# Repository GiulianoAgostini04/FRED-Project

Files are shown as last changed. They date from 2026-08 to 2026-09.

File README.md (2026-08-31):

# FRED-Project
Real-time concentration monitoring system based on frontal-lobe EEG signals. Features a custom PCB designed with TinkerCAD and KiCad, OpenBCI Ganglion and Arduino UNO for signal acquisition, display, and frequency-band analysis for classification. Includes circuit schematics, hardware prototyping, and a VHDL model of the decision logic.

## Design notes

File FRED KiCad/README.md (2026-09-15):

# FRED: KiCad Section

This repository contains the KiCad design files for FRED (Focus-Related Encephalographic Device), a custom EEG acquisition board developed for an electronic engineering course project.

The board handles the full analog front-end for EEG signal acquisition (electrode input, protection, channel multiplexing, instrumentation amplification, filtering, galvanic isolation, output buffering) and a digital channel-selection block, and sends the processed signal to an Arduino for further analysis and display.

## Board overview

The design includes:

- Electrode input stage with protection and a DRL (Driven Right Leg) reference stage for common-mode rejection
- CD4052B dual multiplexer for electrode channel selection
- INA128 instrumentation amplifier
- Sallen-Key high-pass filter (fc = 1 Hz)
- Fixed-gain amplification stage (A = 10)
- 50 Hz Twin-T notch filter
- Galvanic isolation stage based on NE555 PWM modulation, a 4N35 optocoupler, and Sallen-Key demodulation
- Anti-aliasing band-pass filter and output buffer toward the Arduino ADC
- Digital block for channel selection (slide switches, 74HC74 flip-flop, 74HC04/74HC08 logic, status LEDs)

Note: intermediate export files (`.cad`, `.cmp`, `.dsn`, `.emn`, `.emp`, `.hyp`, `.wrl`) and auto-generated check reports (`DRC.rpt`, `ERC.rpt`, `report.txt`) are not versioned, since they can be regenerated at any time from the project files.

## Tools used

| Tool | Purpose |
|---|---|
| KiCad 10.0 | Schematic and PCB layout |

## How to open the project

1. Clone the repository.
2. Open `FRED_Electrical_Scheme_KiCAD.kicad_pro` with KiCad 10.0 or later.
3. Schematic and PCB print PDFs are available in the `PDF/` folder for a quick look without opening KiCad.

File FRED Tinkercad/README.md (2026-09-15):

# FRED: TinkerCAD Section

The circuit reproduces the full analog front-end on breadboards, together with the digital channel-selection block, and connects to an Arduino Uno driving an LCD 16x2 display.

## Circuit overview

The prototype implements, stage by stage:

- Three 741 op-amps configured as the instrumentation amplifier (INA)
- A Sallen-Key high-pass filter stage (HPF)
- A fixed-gain amplification stage (Amplif1)
- A Twin-T notch filter at 50 Hz
- A galvanic isolation stage based on a 555 timer (PWM modulation), an optocoupler, and a low-pass demodulation filter (LPF)
- An anti-aliasing band-pass filter (BPF)
- A final output amplification stage before the Arduino input
- A digital channel-selection block built from a dual D flip-flop, an inverter array, and a quad AND gate, with status LEDs
- An Arduino Uno R3 reading the processed signal and driving an LCD 16x2 display

## Bill of materials (summary)

| Component | Qty | Notes |
|---|---|---|
| 741 op-amp | 10 | INA (x3), HPF, Amplif1, Notch Twin-T, LPF, BPF, Exit Amplif, U1 |
| Breadboard | 3 | Full-size |
| Breadboard mini | 9 | |
| 555 timer | 1 | Isolation stage PWM modulator |
| Optocoupler | 1 | Isolation stage |
| Quad AND gate | 1 | Channel-selection LED decoding |
| Dual D flip-flop | 1 | Channel-selection logic |
| Hex inverter | 1 | Channel-selection logic |
| Slide switch | 2 | Channel selection input |
| Pushbutton | 1 | Clock for the flip-flop |
| Red LED | 4 | Channel status indicators |
| Arduino Uno R3 | 1 | Signal processing and LCD driving |
| LCD 16x2 | 1 | Display output |
| Resistors, various values | 30+ | See CSV for full list with reference designators |
| Capacitors, various values | 11 | See CSV for full list with reference designators |

The complete list with reference designators and exact values is in `FRED_Circuit_Prototype_Components.csv`.
Tinkercad link: https://www.tinkercad.com/things/7vpgewQdkgf-fred-project-tinkercad-prototype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

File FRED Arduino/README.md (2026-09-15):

# FRED: Arduino Section

Arduino firmware for EEG band-power analysis and focus/not-focus state estimation, with output on a 16x2 LCD.

## How it works

1. A **Timer1** in CTC mode samples the signal at **256 Hz** via interrupt, filling a window of **256 samples**.
2. Once the window is full, the power of each band is computed with the **Goertzel algorithm**
3. The **dominant band** (highest power) is identified.
4. **Focus** state is assigned when the dominant band is Beta.
5. Results are printed over **Serial (115200 baud)** and shown on the **16x2 LCD**.

## Files

- `FREDARDUINOSCRIPT.ino` — main sketch 
- `wdt_init.cpp` — disables the Watchdog Timer at boot before `setup()` runs. Prevents the classic infinite reset loop on Arduino Uno when the watchdog is left enabled by a previous reset

## Usage

1. Open `FREDARDUINOSCRIPT.ino` in the Arduino IDE (make sure `wdt_init.cpp` is in the same sketch folder)
2. Select **Arduino Uno** as the board and the correct serial port
3. Upload the sketch
4. Open the Serial Monitor at **115200 baud** for the detailed band-power log

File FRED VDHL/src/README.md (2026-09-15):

# FRED: VHDL Section

## Modules

### `channel_selector`
Models the digital channel-selection block. On the rising edge of `btn`, the 2-bit input `sw` is latched into the output `q`, which selects one of four channels. The four outputs in `led` are a one-hot decoding of `q`, used to drive the status LEDs.

| Port | Direction | Type | Description |
|---|---|---|---|
| `sw` | in | `std_logic_vector(1 downto 0)` | Channel selection switches |
| `btn` | in | `std_logic` | Latches `sw` into the output on its rising edge |
| `q` | out | `std_logic_vector(1 downto 0)` | Selected channel |
| `led` | out | `std_logic_vector(3 downto 0)` | One-hot LED indicator for the selected channel |

### `focus_comparator`
Models the classification logic between a "focus" and a "not focus" state, based on two 8-bit inputs, with dual-threshold hysteresis to avoid state chattering around the decision boundary.

| Port | Direction | Type | Description |
|---|---|---|---|
| `clk` | in | `std_logic` | Clock |
| `rstas` | in | `std_logic` | Asynchronous active-low reset |
| `focus_in` | in | `std_logic_vector(7 downto 0)` | Focus-related band power |
| `notFocus_in` | in | `std_logic_vector(7 downto 0)` | Not-focus-related band power |
| `data_valid` | in | `std_logic` | Qualifies when the inputs are valid and the state may update |
| `ledFocus` | out | `std_logic` | High when the FSM is in the focus state |
| `ledNotFocus` | out | `std_logic` | High when the FSM is in the not-focus state |

The FSM computes `diff = focus_in - notFocus_in` and switches from not-focus to focus when `diff` exceeds `threshold_focus` (15), and back from focus to not-focus when `diff` drops below `threshold_not_focus` (5). Between the two thresholds the state is held, which is the hysteresis dead zone.

---

## Status

Both modules are complete and verified in GTKWave against their testbenches.

- `channel_selector`: verified across all four switch combinations, latch-on-button behavior confirmed
- `focus_comparator`: verified including reset behavior, transition above the focus threshold, transition below the not-focus threshold, and correct state holding inside the dead zone

Next step: development of `alpha_beta_comparator`, the core module that will classify the concentration state directly from the alpha/beta band power values.

## Tools used

| Tool | Purpose |
|---|---|
| VS Code + TerosHDL | VHDL editing |
| GHDL 6.0.0 | Compilation and simulation |
| GTKWave 3.3.100 | Waveform visualization |

---

## How to simulate

From the folder containing the source and testbench file:

```bash
ghdl -a channel_selector.vhd channel_selector_tb.vhd
ghdl -e channel_selector_tb
ghdl -r channel_selector_tb --wave=channel_selector.ghw
gtkwave channel_selector.ghw
```

```bash
ghdl -a focus_comparator.vhd focus_comparator_tb.vhd
ghdl -e focus_comparator_tb
ghdl -r focus_comparator_tb --wave=focus_comparator.ghw --stop-time=250ns
gtkwave focus_comparator.ghw
```

Note: `focus_comparator_tb` uses a free-running clock (`clk_tb <= not clk_tb after 10 ns`), so the `--stop-time` flag is required to terminate the simulation.

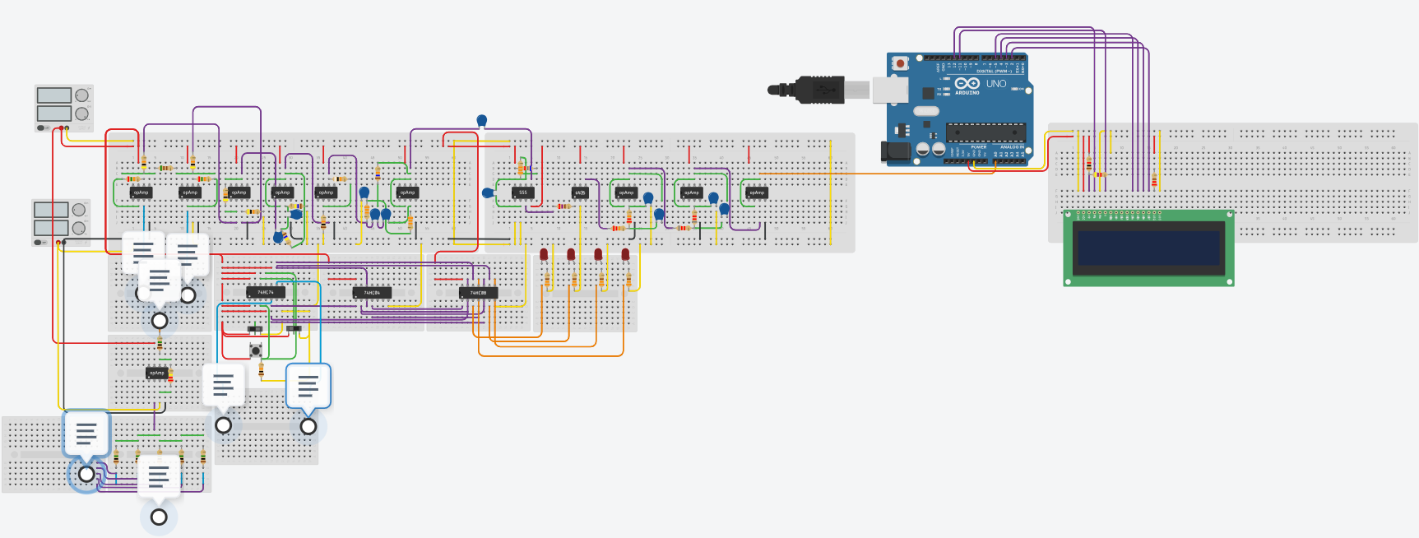
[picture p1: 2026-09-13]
FRED Tinkercad/FRED_Circuit_Prototype.png

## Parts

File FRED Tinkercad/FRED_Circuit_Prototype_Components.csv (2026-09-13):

Nome | Quantità | Componente
Breadboard 11, Breadboard 22, 4 | 3 | Breadboard
UOpAmp1 (INA), UOpAmp2 (INA), UOpAmp3 (INA), UOpAmp4 (HPF), UOpAmp5 (Amplif1), UOpAmp6 (Notch Twin-T), ULPF (Isolation Amplifier), UBPF Antialiasing, UExit Amplif, U1 | 10 | Amplificatore operazionale 741
PAlim +, PAlim - | 2 | 5 , 5 Alimentatore
RR2, RR1 | 2 | 25 kΩ Resistenza
RRG | 1 | 510 Ω Resistenza
RR3, RR4, RR5, RR6 | 4 | 40 kΩ Resistenza
RR7, RR8 | 2 | 160 kΩ Resistenza
CC2, CC1 | 2 | 1 uF Condensatore
RR9, R1 | 2 | 10 kΩ Resistenza
RR10 | 1 | 90 kΩ Resistenza
RR11, RR12, RR_B | 3 | 33 kΩ Resistenza
CC3, CC4 | 2 | 100 nF Condensatore
RR13 | 1 | 16 kΩ Resistenza
CC5 | 1 | 200 nF Condensatore
UAND | 1 | Porta AND quadrupla
UFlip-Flop | 1 | Doppio flip-flop D
1, 2, 5, 6, 3, 7, 13, 15, 17 | 9 | Breadboard mini
S1, S3 | 2 | Interruttore a scorrimento
S2 | 1 | Pulsante
UInverter | 1 | Invertitore sestuplo
UTimer (Isolation Amplifier) | 1 | Timer
RR_A | 1 | 6.8 kΩ Resistenza
CC6 | 1 | 100 uF Condensatore
Uoptocoupler (Isolation Amplifier) | 1 | Optoaccoppiatore
RR_OC | 1 | 270 Ω Resistenza
CC7 | 1 | 1 nF Condensatore
RR15, RR14 | 2 | 22 kΩ Resistenza
CC8, CC9, CC10, CC11 | 4 | 10 nF Condensatore
RR16, RR17 | 2 | 8.2 kΩ Resistenza
D4, D3, D2, D1 | 4 | Rosso LED
U3 | 1 | LCD 16 x 2
U2 | 1 | Arduino Uno R3
R2, R3, R4, R5 | 4 | 330 Ω Resistenza
R6 | 1 | 220 kΩ Resistenza
R7, R8, R9, R10, R11, R12 | 6 | 1 MΩ Resistenza
R13 | 1 | 1 kΩ Resistenza
R14 | 1 | 4.7 kΩ Resistenza
R15 | 1 | 220 Ω Resistenza

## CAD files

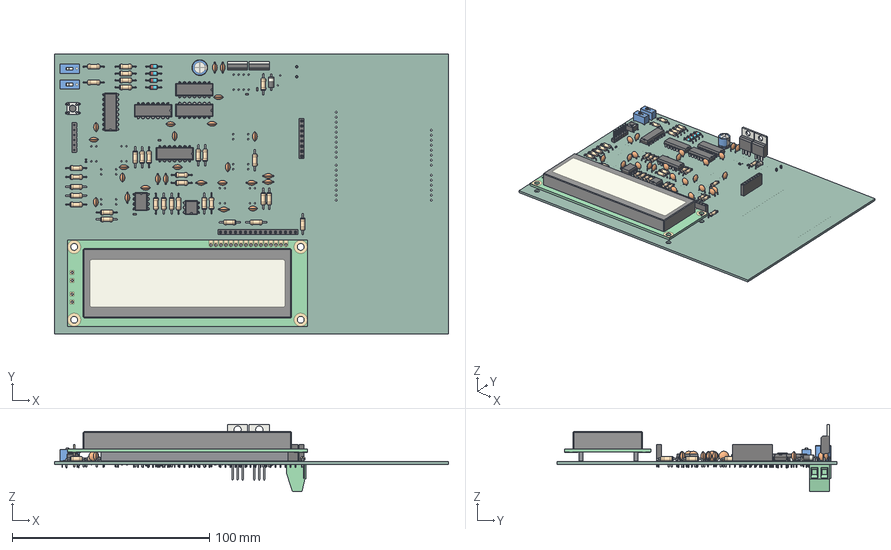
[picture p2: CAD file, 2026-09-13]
FRED KiCad/FRED_Electrical_Scheme_KiCAD.step
200.0 x 142.3 x 34.3 mm
C_Disc_D50mm_W25mm_P500mm x 10
TO-220-3_Vertical x 2
DIP-8_W7.62mm
C_0603_1608Metric x 5
DIP-14_W7.62mm x 4
SW_DIP_SPSTx01_Slide_978x472mm_W762mm_P254mm x 2
R_Axial_DIN0207_L63mm_D25mm_P1016mm_Horizontal x 33
SW_PUSH_6mm
D_DO-35_SOD27_P7.62mm_Horizontal x 4
C_Disc_D50mm_W25mm_P250mm x 15
CP_Radial_D80mm_P350mm
Fusion032_sp
PinSocket_1x08_P2.54mm_Vertical
PinHeader_1x06_P254mm_Vertical
DIP-16_W7.62mm
PinSocket_1x16_P2.54mm_Vertical
DIP-6_W7.62mm
D_A-405_P7.62mm_Horizontal
TerminalBlock_Phoenix_MKDS-1,5-2-5.08_1x02_P5.08mm_Horizontal
FREC3E2_PCB

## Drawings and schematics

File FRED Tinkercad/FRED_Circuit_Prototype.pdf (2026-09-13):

A

1 | 2 | 3 | 4 | 5 | 6

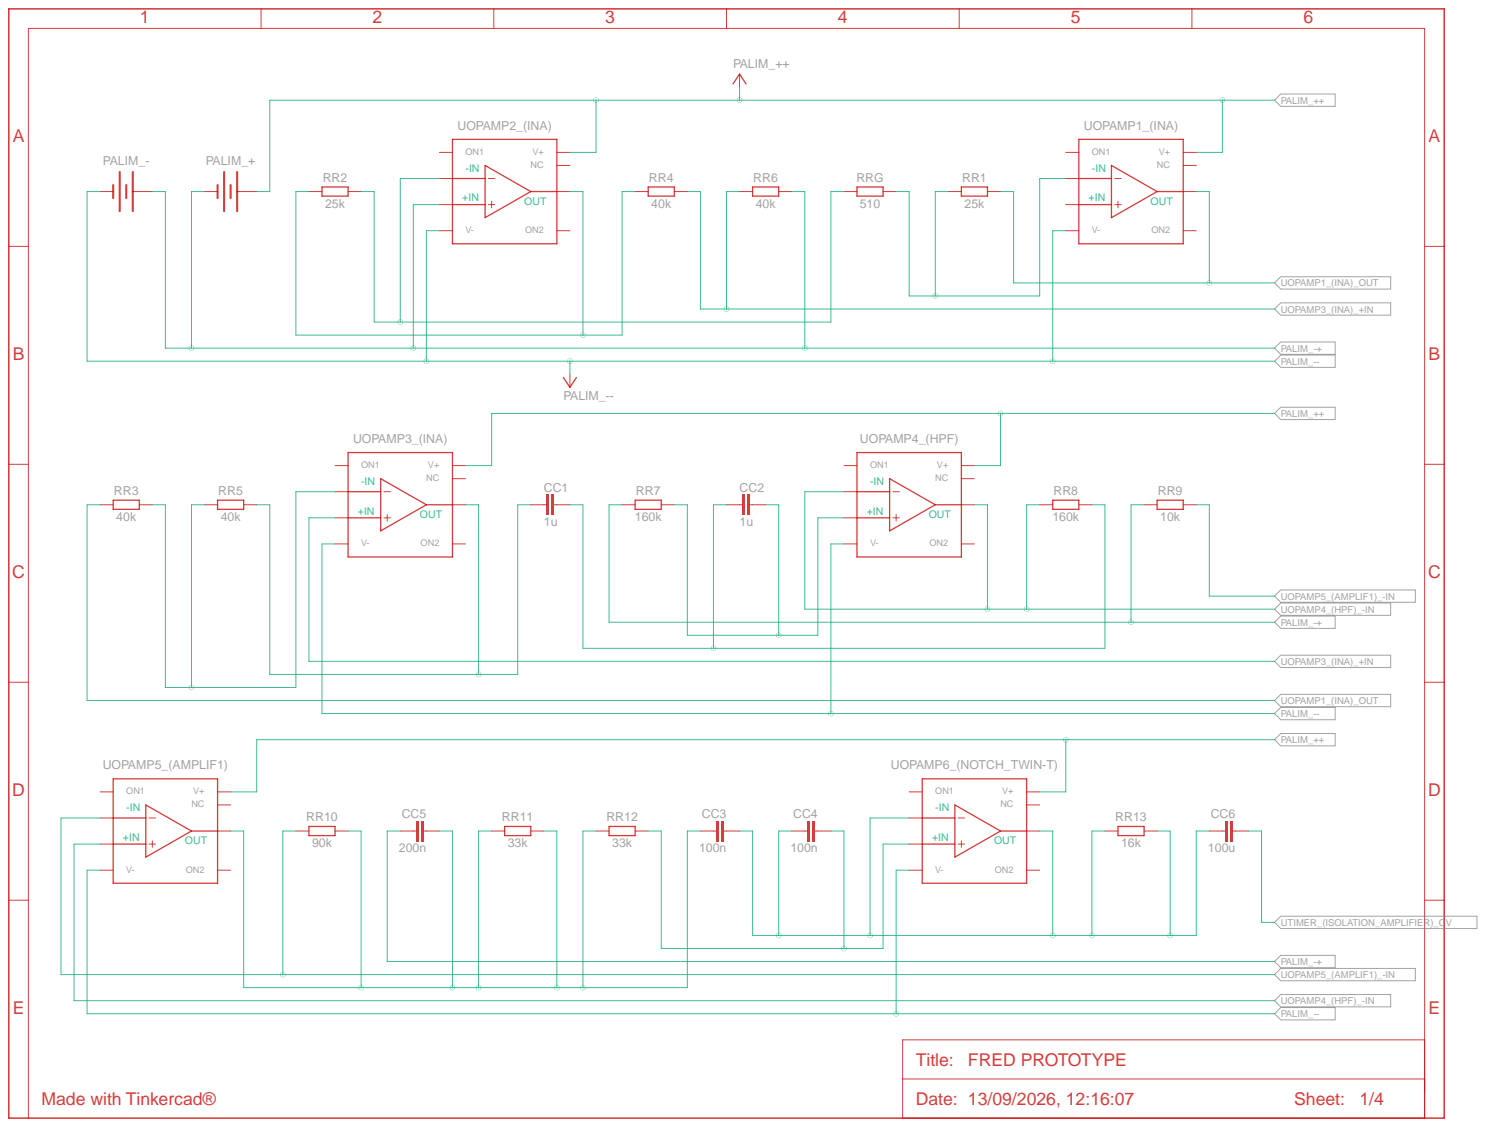
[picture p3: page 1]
Date: 13/09/2026, 12:16:07; Sheet: 1/4; PALIM_-; PALIM_+; UOPAMP2_(INA); OUT; RRG; UOPAMP1_(INA); PALIM_--; UOPAMP3_(INA); UOPAMP4_(HPF); UOPAMP5_(AMPLIF1); UOPAMP6_(NOTCH_TWIN-T); PALIM_-+; PALIM_++; UOPAMP3_(INA)_+IN; UOPAMP1_(INA)_OUT; UOPAMP4_(HPF)_-IN; UOPAMP5_(AMPLIF1)_-IN; UTIMER_(ISOLATION_AMPLIFIER)_CV

PALIM_++

Title: FRED PROTOTYPE

Made with Tinkercad®

A

1 | 2 | 3 | 4 | 5 | 6

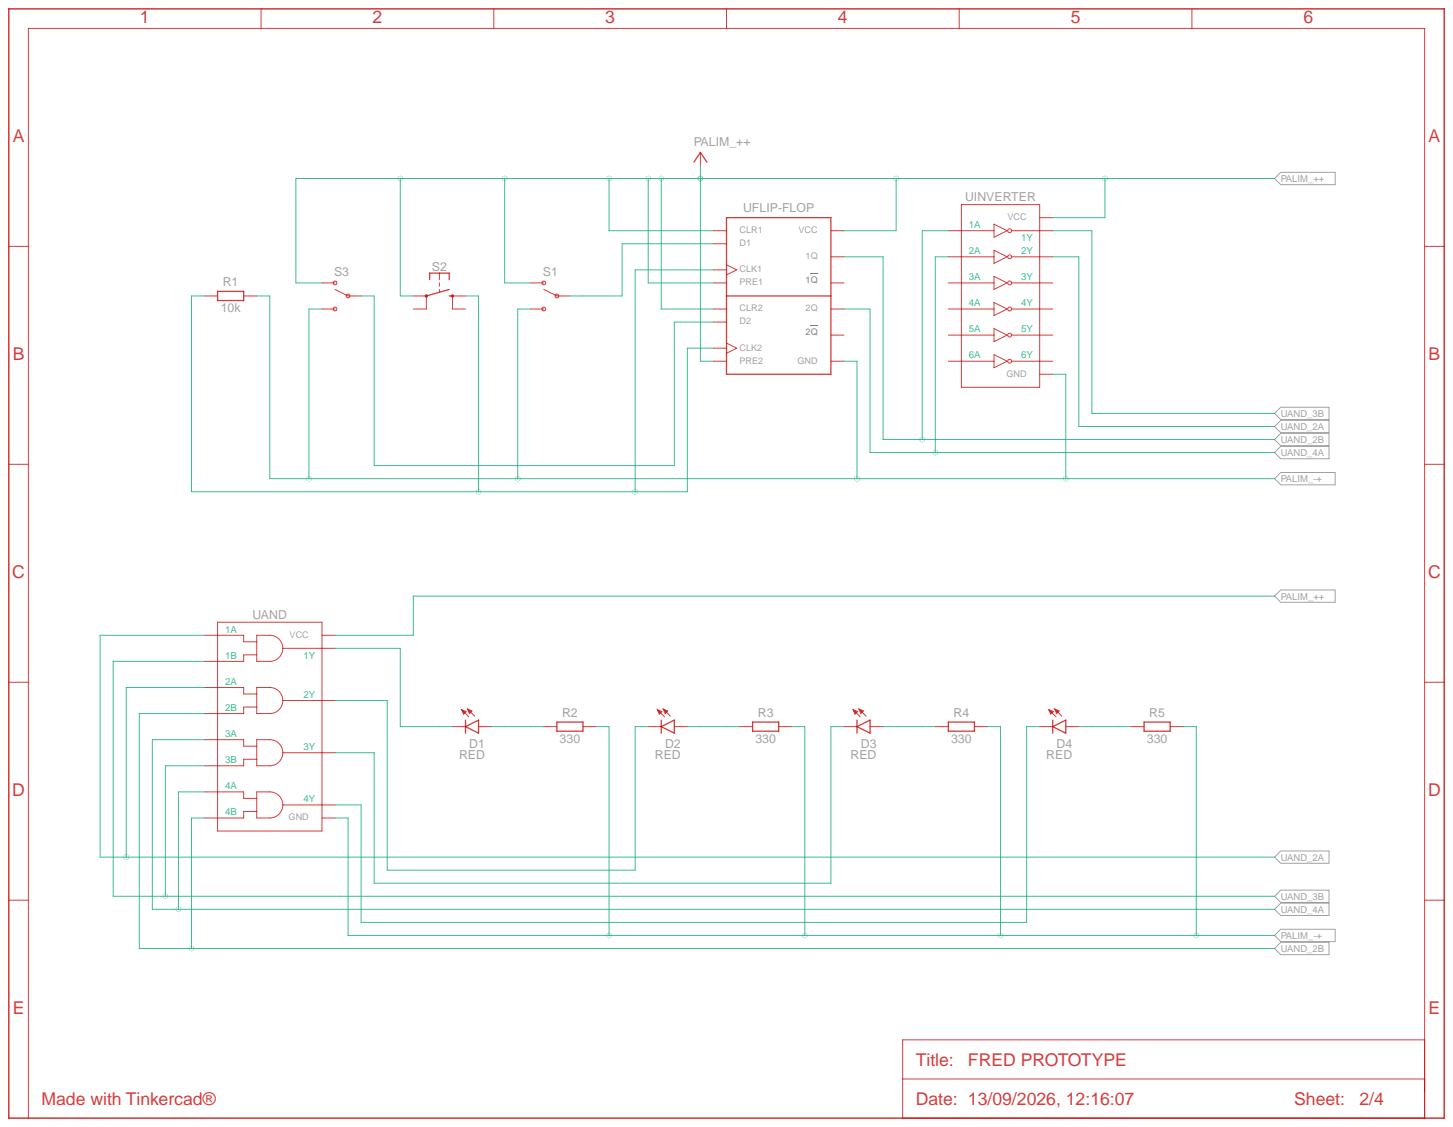
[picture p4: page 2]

A

1 | 2 | 3 | 4 | 5 | 6

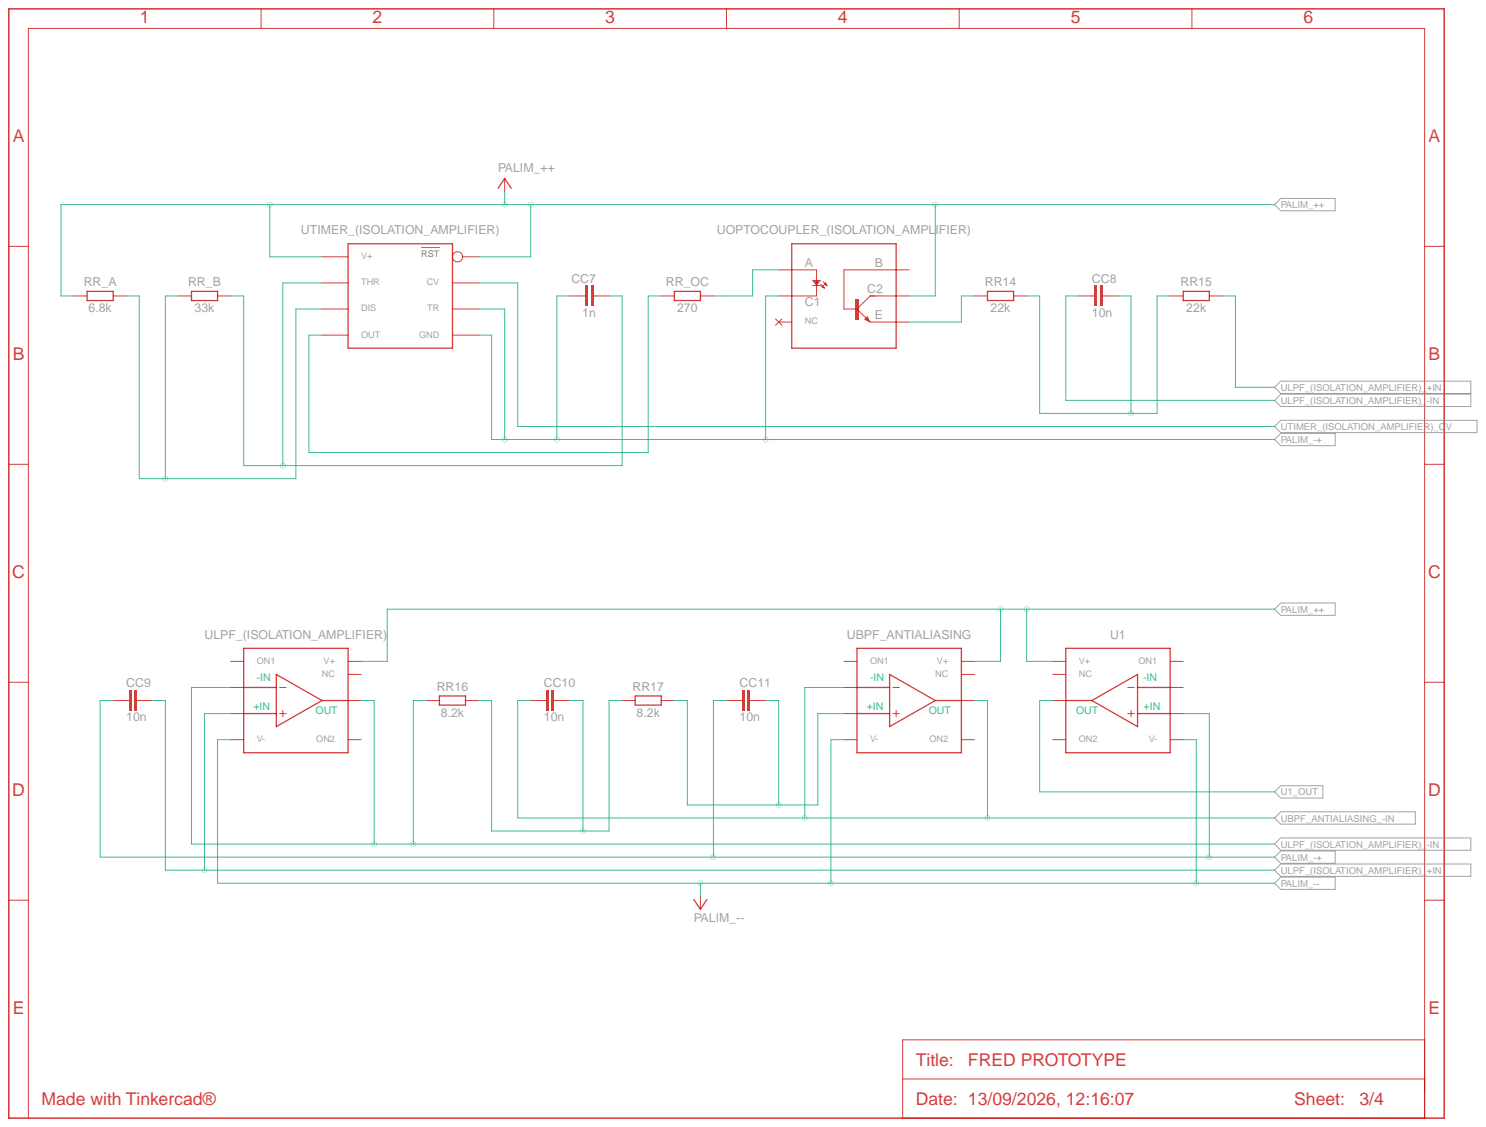
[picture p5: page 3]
Date: 13/09/2026, 12:16:07; Sheet: 3/4; GND; RST; OUT; THR; DIS; UTIMER_(ISOLATION_AMPLIFIER); UOPTOCOUPLER_(ISOLATION_AMPLIFIER); PALIM_++; ULPF_(ISOLATION_AMPLIFIER); UBPF_ANTIALIASING; PALIM_--; PALIM_-+; UTIMER_(ISOLATION_AMPLIFIER)_CV; ULPF_(ISOLATION_AMPLIFIER)_-IN; ULPF_(ISOLATION_AMPLIFIER)_+IN; ULPF_(ISOLATION_AMPLIFIER)_+IN PALIM_--; UBPF_ANTIALIASING_-IN; U1_OUT

Title: FRED PROTOTYPE

Made with Tinkercad®

A

1 | 2 | 3 | 4 | 5 | 6

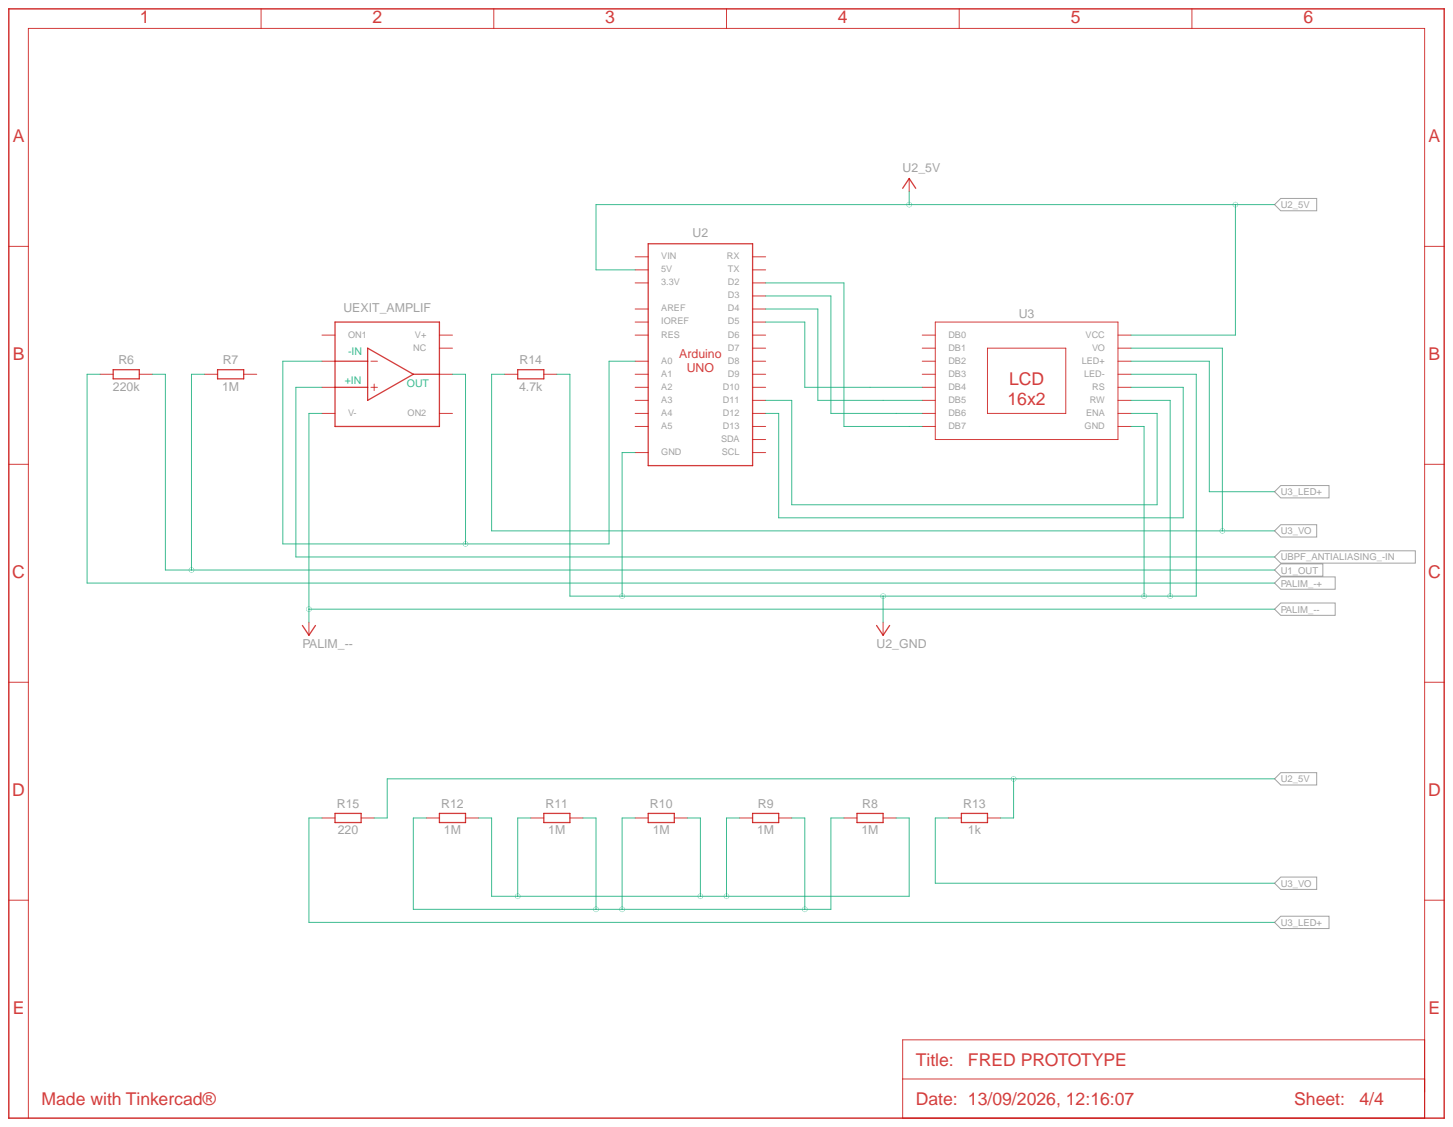
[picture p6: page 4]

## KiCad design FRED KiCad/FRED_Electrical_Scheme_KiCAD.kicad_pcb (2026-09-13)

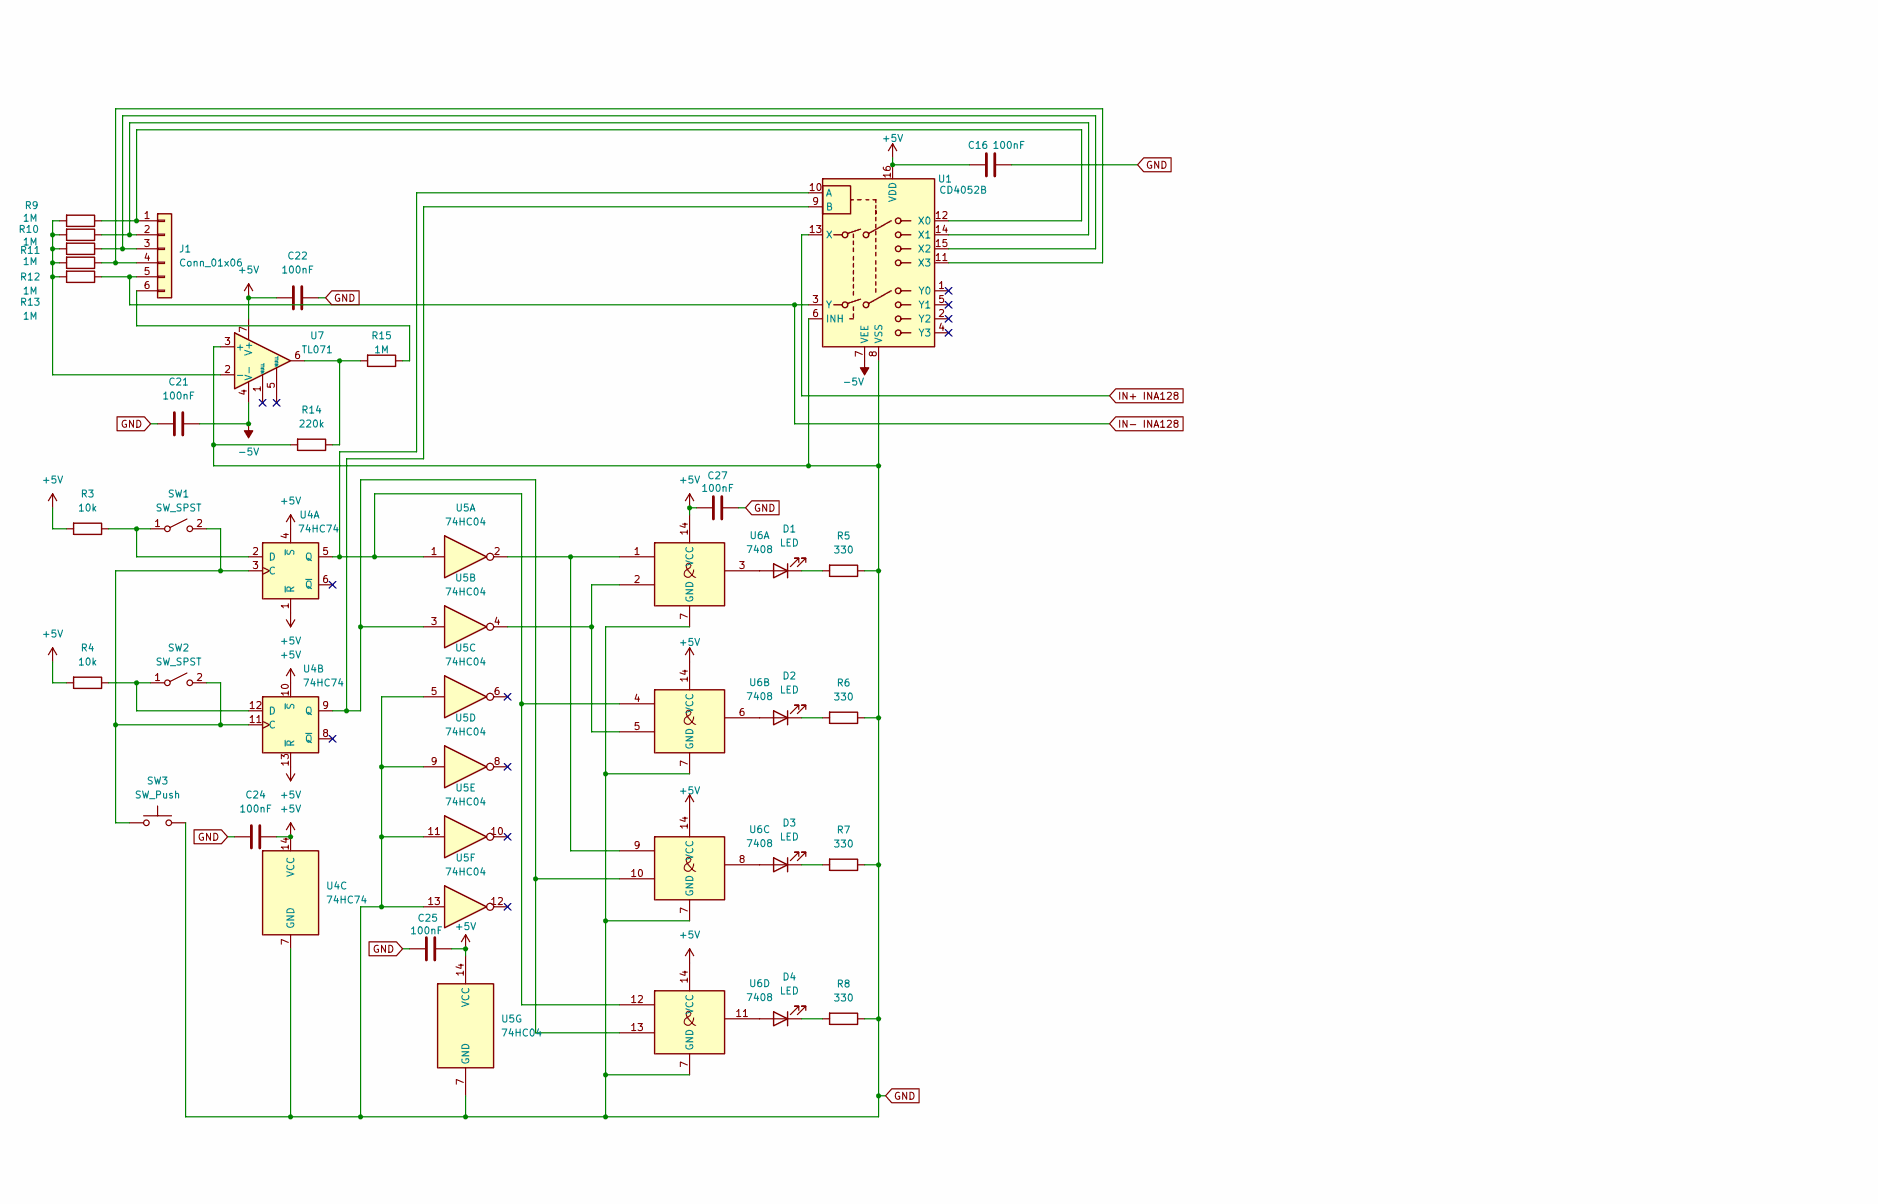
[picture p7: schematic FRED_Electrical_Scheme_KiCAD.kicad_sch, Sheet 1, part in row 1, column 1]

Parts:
C16, C21, C22, C24, C25, C27: 100nF; C_Disc_D5.0mm_W2.5mm_P2.50mm
D1, D2, D3, D4: LED; D_DO-35_SOD27_P7.62mm_Horizontal
J1: Conn_01x06; PinHeader_1x06_P2.54mm_Vertical
R3, R4: 10k; R_Axial_DIN0207_L6.3mm_D2.5mm_P10.16mm_Horizontal
R5, R6, R7, R8: 330; R_Axial_DIN0207_L6.3mm_D2.5mm_P10.16mm_Horizontal
R9, R10, R11, R12, R13, R15: 1M; R_Axial_DIN0207_L6.3mm_D2.5mm_P10.16mm_Horizontal
R14: 220k; R_Axial_DIN0207_L6.3mm_D2.5mm_P10.16mm_Horizontal
SW1, SW2: SW_SPST; SW_DIP_SPSTx01_Slide_9.78x4.72mm_W7.62mm_P2.54mm
SW3: SW_Push; SW_PUSH_6mm
U1: CD4052B; DIP-16_W7.62mm
U4: 74HC74; DIP-14_W7.62mm
U5: 74HC04; DIP-14_W7.62mm
U6: 7408; DIP-14_W7.62mm
U7: TL071; DIP-8-16_W7.62mm

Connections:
+5V: C16.2, C22.2, C24.1, C25.1, C27.2, R3.2, R4.2, U1.16 (VDD), U4.1 (~R), U4.4 (~S), U4.10 (~S), U4.13 (~R), U4.14 (VCC), U5.14 (VCC), U6.14 (VCC), U7.7 (V+); also elsewhere on the board
-5V: C21.1, U1.7 (VEE), U7.4 (V-); also elsewhere on the board
GND: C16.1, C21.2, C22.1, C24.2, C25.2, C27.1, R5.1, R6.1, R7.1, R8.1, R14.2, SW3.2, U1.6 (INH), U1.8 (VSS), U4.7 (GND), U5.5, U5.7 (GND), U5.9, U5.11, U5.13, U6.7 (GND), U7.3 (+); also elsewhere on the board
IN+ INA128: U1.13 (X); also elsewhere on the board
IN- INA128: J1.5, R13.1, U1.3 (Y); also elsewhere on the board
unnamed: D1.2 (A), U6.3
unnamed: D1.1 (K), R5.2
unnamed: D2.2 (A), U6.6
unnamed: D2.1 (K), R6.2
unnamed: D3.2 (A), U6.8
unnamed: D3.1 (K), R7.2
unnamed: D4.2 (A), U6.11
unnamed: D4.1 (K), R8.2
unnamed: J1.1, R9.1, U1.12 (X0)
unnamed: J1.2, R10.1, U1.14 (X1)
unnamed: J1.3, R11.1, U1.15 (X2)
unnamed: J1.4, R12.1, U1.11 (X3)
unnamed: J1.6, R15.1
unnamed: R14.1, R15.2, U7.6
unnamed: R3.1, SW1.1 (A), U4.2 (D)
unnamed: SW1.2 (B), SW2.2 (B), SW3.1, U4.3 (C), U4.11 (C)
unnamed: R4.1, SW2.1 (A), U4.12 (D)
unnamed: U1.10 (A), U4.5 (Q), U5.1, U6.4, U6.12
unnamed: U1.9 (B), U4.9 (Q), U5.3, U6.10, U6.13
unnamed: U5.2, U6.1, U6.9
unnamed: U5.4, U6.2, U6.5
unnamed: R9.2, R10.2, R11.2, R12.2, R13.2, U7.2 (-)

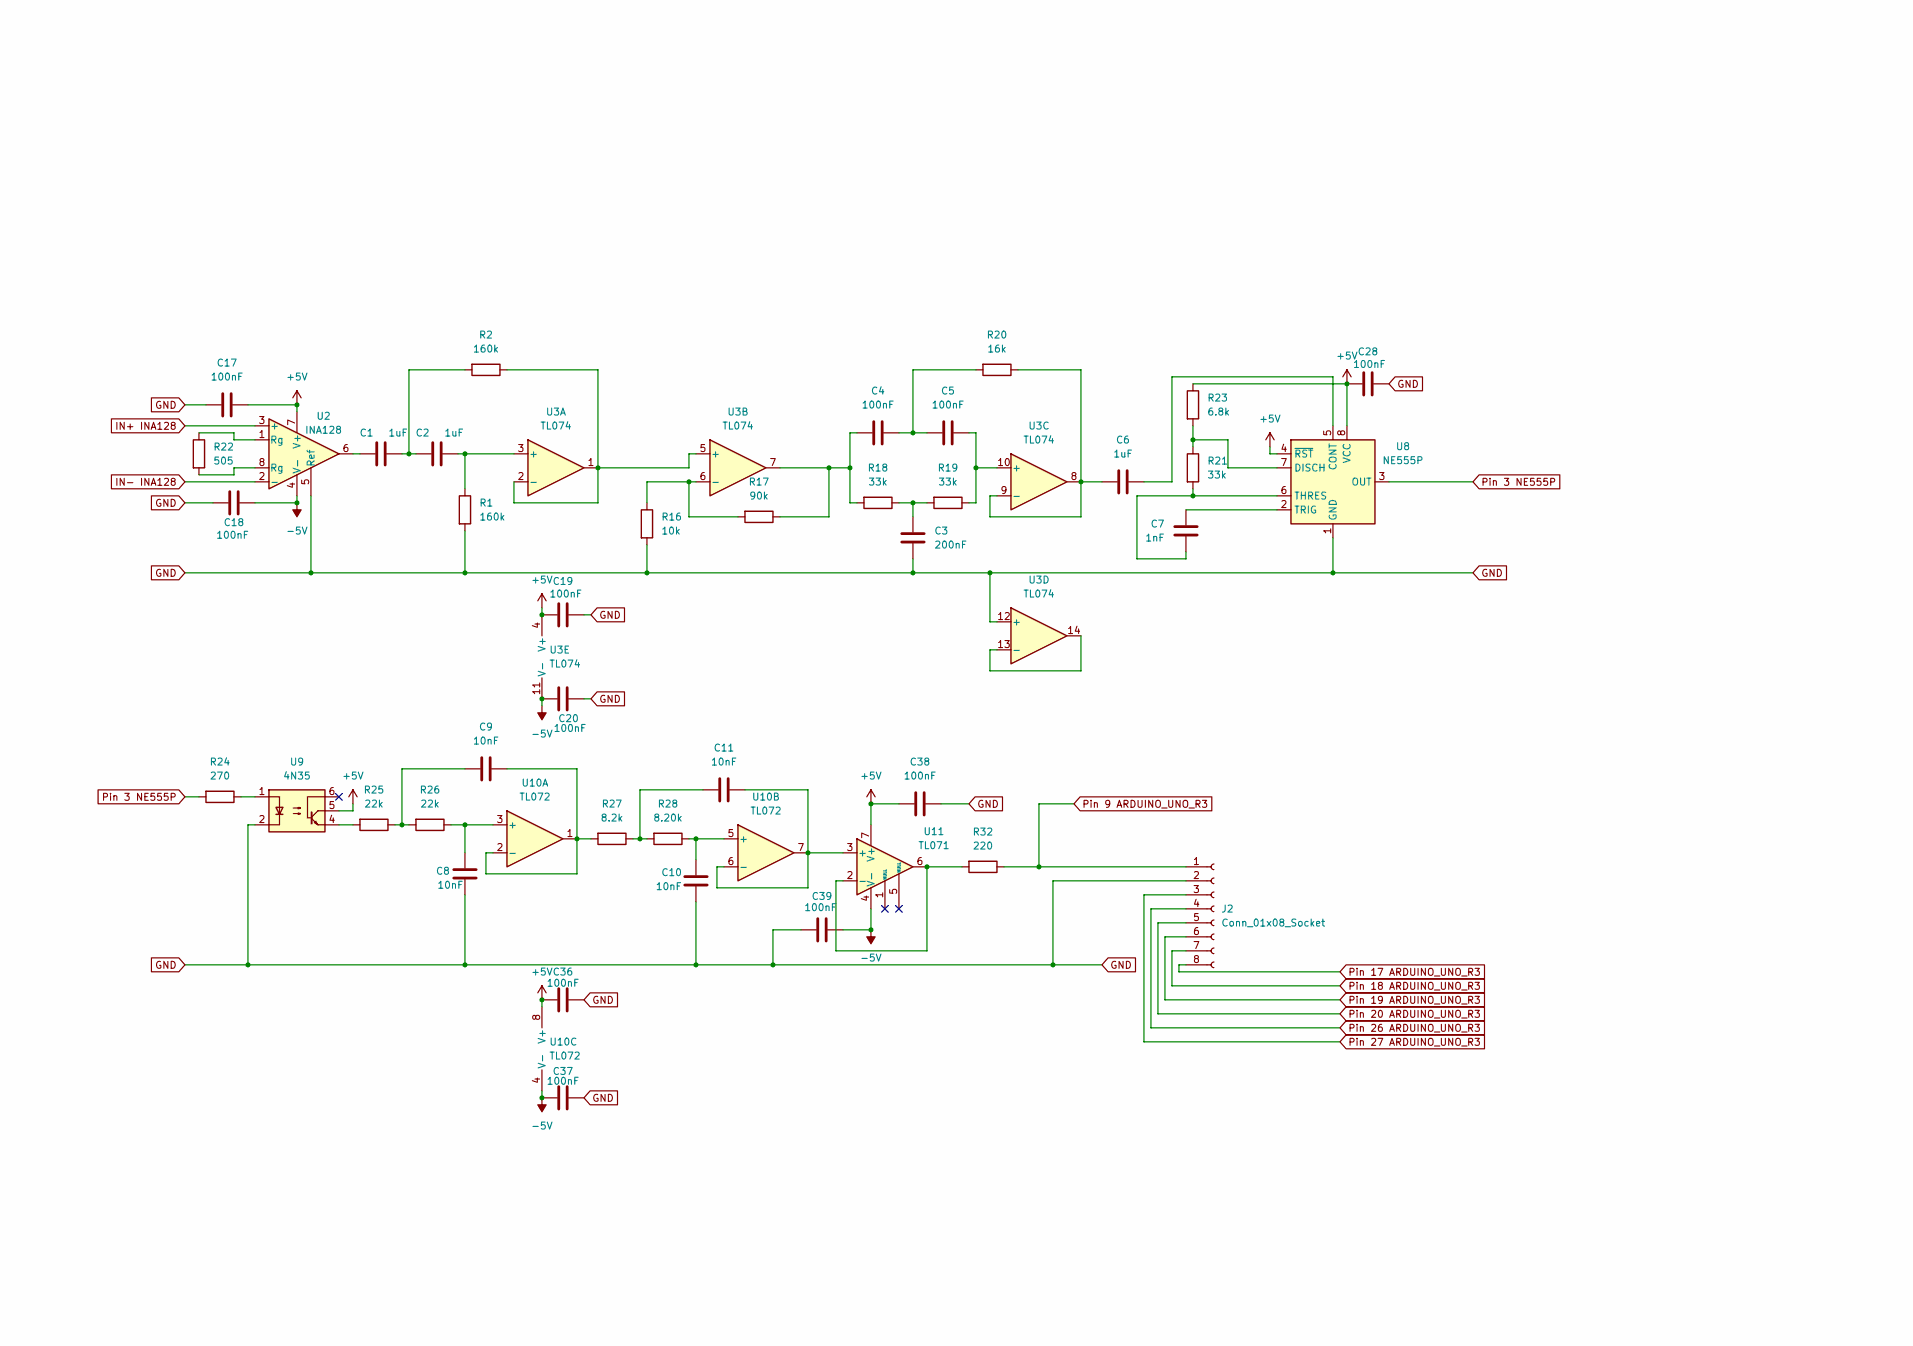
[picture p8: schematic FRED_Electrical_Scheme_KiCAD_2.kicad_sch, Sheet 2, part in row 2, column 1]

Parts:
C1, C2, C6: 1uF; C_0603_1608Metric
C3: 200nF; C_Disc_D5.0mm_W2.5mm_P5.00mm
C4, C5: 100nF; C_Disc_D5.0mm_W2.5mm_P5.00mm
C7: 1nF; C_Disc_D5.0mm_W2.5mm_P5.00mm
C8, C9, C10, C11: 10nF; C_Disc_D5.0mm_W2.5mm_P5.00mm
C17, C18, C19, C20, C28, C36, C37, C38, C39: 100nF; C_Disc_D5.0mm_W2.5mm_P2.50mm
J2: Conn_01x08_Socket; PinSocket_1x08_P2.54mm_Vertical
R1, R2: 160k; R_Axial_DIN0207_L6.3mm_D2.5mm_P10.16mm_Horizontal
R16: 10k; R_Axial_DIN0207_L6.3mm_D2.5mm_P10.16mm_Horizontal
R17: 90k; R_Axial_DIN0207_L6.3mm_D2.5mm_P10.16mm_Horizontal
R18, R19, R21: 33k; R_Axial_DIN0207_L6.3mm_D2.5mm_P10.16mm_Horizontal
R20: 16k; R_Axial_DIN0207_L6.3mm_D2.5mm_P10.16mm_Horizontal
R22: 505; R_Axial_DIN0207_L6.3mm_D2.5mm_P10.16mm_Horizontal
R23: 6.8k; R_Axial_DIN0207_L6.3mm_D2.5mm_P10.16mm_Horizontal
R24: 270; R_Axial_DIN0207_L6.3mm_D2.5mm_P10.16mm_Horizontal
R25, R26: 22k; R_Axial_DIN0207_L6.3mm_D2.5mm_P10.16mm_Horizontal
R27: 8.2k; R_Axial_DIN0207_L6.3mm_D2.5mm_P10.16mm_Horizontal
R28: 8.20k; R_Axial_DIN0207_L6.3mm_D2.5mm_P10.16mm_Horizontal
R32: 220; R_Axial_DIN0207_L6.3mm_D2.5mm_P10.16mm_Horizontal
U2: INA128; DIP-8-16_W7.62mm
U3: TL074; DIP-14_W7.62mm
U8: NE555P; DIP-8_W7.62mm
U9: 4N35; DIP-6_W7.62mm
U10: TL072; DIP-8-16_W7.62mm
U11: TL071; DIP-8-16_W7.62mm

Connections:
+5V: C17.1, C19.1, C28.2, C36.2, C38.2, R23.1, U2.7 (V+), U3.4 (V+), U8.4 (~RST), U8.8 (VCC), U9.5, U10.8 (V+), U11.7 (V+); also elsewhere on the board
-5V: C18.1, C20.2, C37.2, C39.1, U2.4 (V-), U3.11 (V-), U10.4 (V-), U11.4 (V-); also elsewhere on the board
GND: C3.2, C8.2, C10.2, C17.2, C18.2, C19.2, C20.1, C28.1, C36.1, C37.1, C38.1, C39.2, J2.2, R1.2, R16.2, U2.5 (Ref), U3.12 (+), U8.1 (GND), U9.2; also elsewhere on the board
IN+ INA128: U2.3 (+); also elsewhere on the board
IN- INA128: U2.2 (-); also elsewhere on the board
unnamed: C1.1, U2.6
unnamed: C1.2, C2.1, R2.2
unnamed: C3.1, R18.1, R19.2
unnamed: C4.1, C5.2, R20.2
unnamed: C4.2, R17.1, R18.2, U3.7
unnamed: C9.2, R25.1, R26.2
unnamed: C11.2, R27.1, R28.2
unnamed: R22.1, U2.1 (Rg)
unnamed: R22.2, U2.8 (Rg)
unnamed: R24.1, U9.1
unnamed: R25.2, U9.4
unnamed: C2.2, R1.1, U3.3 (+)
unnamed: R2.1, U3.1, U3.2 (-), U3.5 (+)
unnamed: R16.1, R17.2, U3.6 (-)
unnamed: C5.1, R19.1, U3.10 (+)
unnamed: C6.2, R20.1, U3.8, U3.9 (-)
unnamed: U3.13 (-), U3.14
unnamed: C6.1, U8.5 (CONT)
unnamed: R21.1, R23.2, U8.7 (DISCH)
unnamed: C7.1, R21.2, U8.6 (THRES)
unnamed: C7.2, U8.2 (TRIG)
unnamed: C8.1, R26.1, U10.3 (+)
unnamed: C9.1, R27.2, U10.1, U10.2 (-)
unnamed: C10.1, R28.1, U10.5 (+)
unnamed: C11.1, U10.6 (-), U10.7, U11.3 (+)
unnamed: R32.2, U11.2 (-), U11.6
Pin 3 NE555P: R24.2, U8.3 (OUT)
Pin 9 ARDUINO_UNO_R3: J2.1, R32.1; also elsewhere on the board
Pin 17 ARDUINO_UNO_R3: J2.8; also elsewhere on the board
Pin 18 ARDUINO_UNO_R3: J2.7; also elsewhere on the board
Pin 19 ARDUINO_UNO_R3: J2.6; also elsewhere on the board
Pin 20 ARDUINO_UNO_R3: J2.5; also elsewhere on the board
Pin 26 ARDUINO_UNO_R3: J2.4; also elsewhere on the board
Pin 27 ARDUINO_UNO_R3: J2.3; also elsewhere on the board

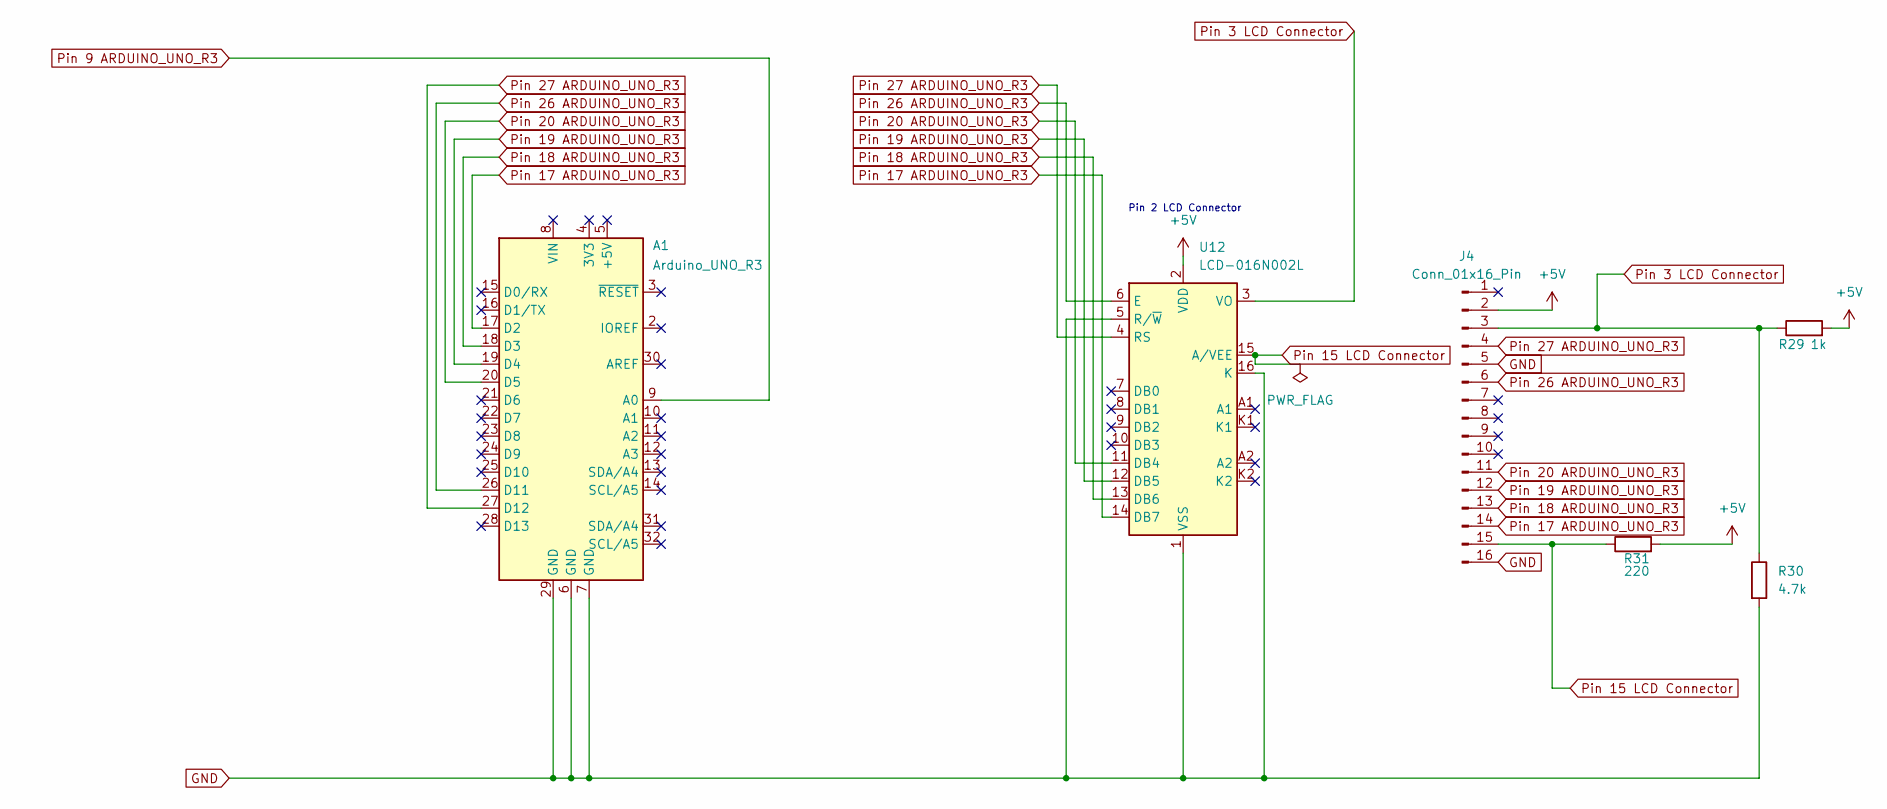
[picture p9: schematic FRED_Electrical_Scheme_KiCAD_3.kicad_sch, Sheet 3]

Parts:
A1: Arduino_UNO_R3
J4: Conn_01x16_Pin; PinSocket_1x16_P2.54mm_Vertical
R29: 1k; R_Axial_DIN0207_L6.3mm_D2.5mm_P10.16mm_Horizontal
R30: 4.7k; R_Axial_DIN0207_L6.3mm_D2.5mm_P10.16mm_Horizontal
R31: 220; R_Axial_DIN0207_L6.3mm_D2.5mm_P10.16mm_Horizontal
U12: LCD-016N002L

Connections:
+5V: J4.2, R29.2, R31.2, U12.2 (VDD); also elsewhere on the board
GND: A1.6 (GND), A1.7 (GND), A1.29 (GND), J4.5, J4.16, R30.2, U12.1 (VSS), U12.5 (R/~W), U12.16 (K); also elsewhere on the board
Pin 3 LCD Connector: J4.3, R29.1, R30.1, U12.3 (VO)
Pin 9 ARDUINO_UNO_R3: A1.9 (A0); also elsewhere on the board
Pin 15 LCD Connector: J4.15, R31.1, U12.15 (A/VEE)
Pin 17 ARDUINO_UNO_R3: A1.17 (D2), J4.14, U12.14 (DB7); also elsewhere on the board
Pin 18 ARDUINO_UNO_R3: A1.18 (D3), J4.13, U12.13 (DB6); also elsewhere on the board
Pin 19 ARDUINO_UNO_R3: A1.19 (D4), J4.12, U12.12 (DB5); also elsewhere on the board
Pin 20 ARDUINO_UNO_R3: A1.20 (D5), J4.11, U12.11 (DB4); also elsewhere on the board
Pin 26 ARDUINO_UNO_R3: A1.26 (D11), J4.6, U12.6 (E); also elsewhere on the board
Pin 27 ARDUINO_UNO_R3: A1.27 (D12), J4.4, U12.4 (RS); also elsewhere on the board

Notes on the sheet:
Pin 2 LCD Connector

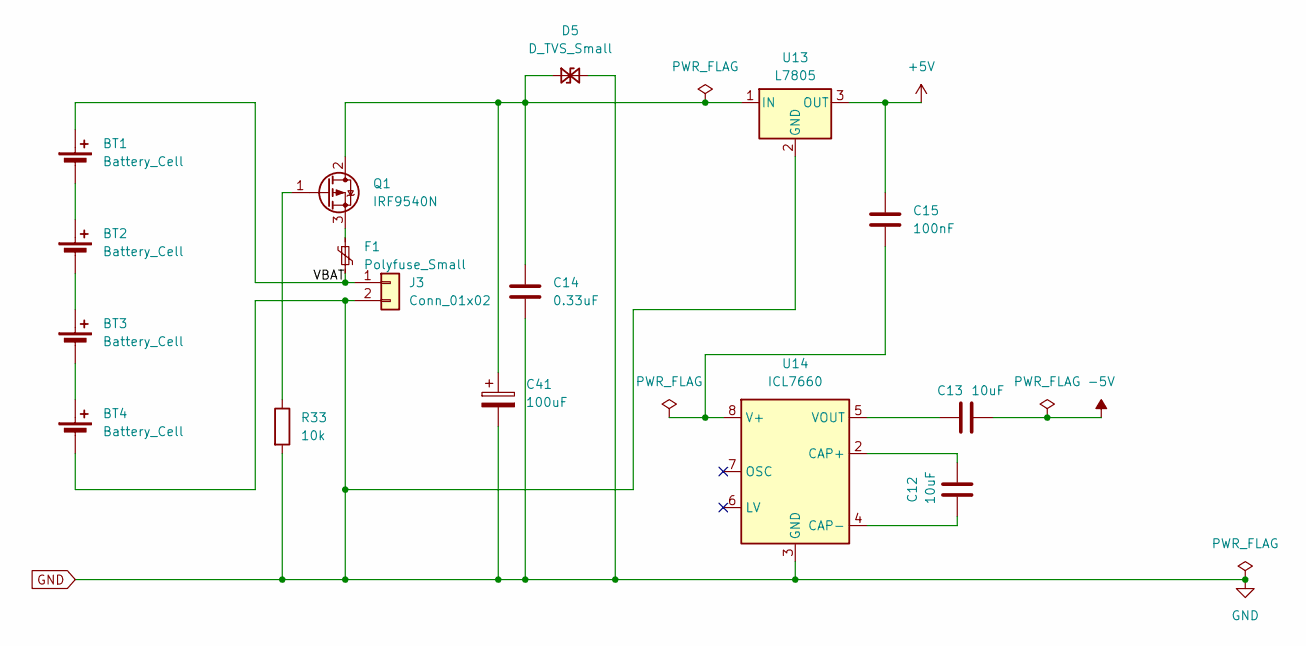
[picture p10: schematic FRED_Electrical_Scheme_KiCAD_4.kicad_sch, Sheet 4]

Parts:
BT1, BT2, BT3, BT4: Battery_Cell
C12, C13: 10uF; C_0603_1608Metric
C14: 0.33uF; C_Disc_D5.0mm_W2.5mm_P5.00mm
C15: 100nF; C_Disc_D5.0mm_W2.5mm_P5.00mm
C41: 100uF; CP_Radial_D8.0mm_P3.50mm
D5: D_TVS_Small; D_A-405_P7.62mm_Horizontal
F1: Polyfuse_Small; Fuse_Bourns_MF-RHT050
J3: Conn_01x02; TerminalBlock_Phoenix_MKDS-1,5-2-5.08_1x02_P5.08mm_Horizont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
Q1: IRF9540N; TO-220-3_Vertical
R33: 10k; R_Axial_DIN0207_L6.3mm_D2.5mm_P10.16mm_Horizontal
U13: L7805; TO-220-3_Vertical
U14: ICL7660; CERDIP-8_W7.62mm_SideBrazed

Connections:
+5V: C15.1, U13.3 (OUT); also elsewhere on the board
-5V: C13.1; also elsewhere on the board
/Sheet 2/Sheet 4/VBAT: BT1.1 (+), F1.2, J3.1
GND: BT4.2 (-), C14.2, C41.2, D5.2 (A2), J3.2, R33.2, U13.2 (GND), U14.3 (GND); also elsewhere on the board
unnamed: BT1.2 (-), BT2.1 (+)
unnamed: BT2.2 (-), BT3.1 (+)
unnamed: BT3.2 (-), BT4.1 (+)
unnamed: C14.1, C41.1, D5.1 (A1), Q1.2 (D), U13.1 (IN)
unnamed: Q1.1 (G), R33.1
unnamed: F1.1, Q1.3 (S)
unnamed: C12.1, U14.2 (CAP+)
unnamed: C12.2, U14.4 (CAP-)
unnamed: C15.2, U14.8 (V+)
unnamed: C13.2, U14.5 (VOUT)

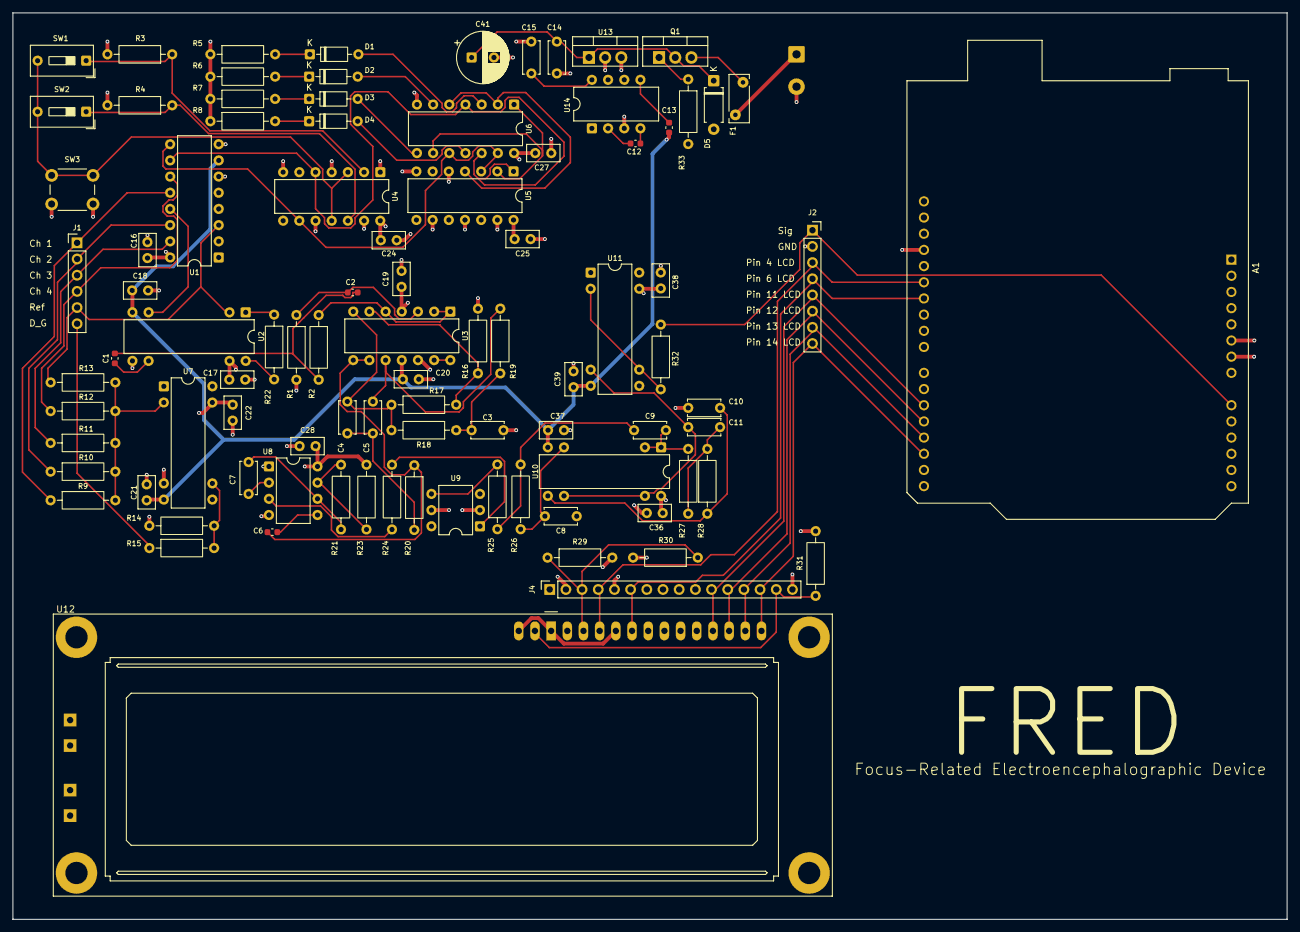
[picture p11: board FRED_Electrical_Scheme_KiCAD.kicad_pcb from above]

Board: 4 copper layers, 200.0 x 142.3 mm, 93 parts (1 on the bottom side), 71 nets.

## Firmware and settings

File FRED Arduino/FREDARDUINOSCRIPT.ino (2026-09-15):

#include <Arduino.h>
#include <math.h>
#include <LiquidCrystal.h>


// LCD (16x2, 4-bit mode)
LiquidCrystal lcd(12, 11, 5, 4, 3, 2);


// PARAMETERS
const uint16_t windowSize = 256;
const float samplingFrequency = 256.0;

// SIMULATION MODALITY
const bool simulationMode = true;

// FREQUENCY OF THE SIMULATED SIGNAL
// 2 Hz  -> Delta
// 6 Hz  -> Theta
// 10 Hz -> Alpha
// 20 Hz -> Beta
// 40 Hz -> Gamma
const float simulatedFrequency = 20.0;

// AMPLITUDE OF THE SIMULATED SIGNAL
const float simulatedAmplitude = 100.0;

// AMPLITUDE OF THE SIMULATED NOISE
const float noiseAmplitude = 10.0;

// BUFFER
// Buffer used by the Interrupt
volatile uint16_t sampleBuffer[windowSize];

// Copy of the processing used window
uint16_t processingBuffer[windowSize];

volatile uint16_t sampleIndex = 0;
volatile bool windowReady = false;

// TIMER 1
void setupTimer1() {

  noInterrupts();

  TCCR1A = 0;
  TCCR1B = 0;
  TCNT1 = 0;

  // 16 MHz / 64 / (976 + 1) = 256 Hz
  OCR1A = 976;

  // CTC mode
  TCCR1B |= (1 << WGM12);

  // Prescaler 64
  TCCR1B |= (1 << CS11) | (1 << CS10);

  // Interrupt
  TIMSK1 |= (1 << OCIE1A);

  interrupts();
}

// INTERRUPT
ISR(TIMER1_COMPA_vect) {

  if (sampleIndex < windowSize) {
    if (simulationMode) {
      // Sample Time
      float t =
        (float)sampleIndex / samplingFrequency;

      // Sinusoidal Signal
      float signal =
        simulatedAmplitude *
        sin(2.0 * PI * simulatedFrequency * t);

      // Random Noise
      float noise =
        ((float)random(-100, 101) / 100.0)
        * noiseAmplitude;

      // Centered Signal at half ADC scale
      float value =
        512.0 + signal + noise;

      // Limits of ADC
      if (value < 0)
        value = 0;

      if (value > 1023)
        value = 1023;

      sampleBuffer[sampleIndex] =
        (uint16_t)value;

    }
    else {
      // Real EEG
      sampleBuffer[sampleIndex] =
        analogRead(A0);
    }

    sampleIndex++;
  }
  else {
    windowReady = true;
  }
}

// GOERTZEL
float goertzelPower(
  uint16_t targetFrequency,
  float mean
) {

  float omega =
    (2.0 * PI * targetFrequency)
    / windowSize;

  float coeff =
    2.0 * cos(omega);

  float q0;
  float q1 = 0.0;
  float q2 = 0.0;

  for (uint16_t i = 0; i < windowSize; i++) {
    float sample =
      (float)processingBuffer[i] - mean;

    q0 =
      coeff * q1
      - q2
      + sample;

    q2 = q1;
    q1 = q0;
  }

  return
    q1 * q1
    + q2 * q2
    - coeff * q1 * q2;
}

// AVERAGE BAND POWER
float calculateBandPower(
  uint16_t lowFrequency,
  uint16_t highFrequency,
  float mean
) {

  float totalPower = 0.0;
  uint16_t numberOfBins =
    highFrequency - lowFrequency + 1;

  for (
    uint16_t f = lowFrequency;
    f <= highFrequency;
    f++
  ) {
    totalPower +=
      goertzelPower(f, mean);
  }

  // Normalisation based on the frequency number
  return totalPower / numberOfBins;
}

// SETUP
void setup() {

  Serial.begin(115200);

  randomSeed(analogRead(A5));

  Serial.println();
  Serial.println("EEG BAND ANALYSIS");
  Serial.println("Arduino Uno R3");

  Serial.print("Sampling frequency: ");
  Serial.print(samplingFrequency);
  Serial.println(" Hz");

  Serial.print("Window size: ");
  Serial.println(windowSize);

  Serial.print("Frequency resolution: ");
  Serial.print(
    samplingFrequency / windowSize
  );
  Serial.println(" Hz");

  Serial.println();

  if (simulationMode) {
    Serial.println("MODE: SIMULATION");

    Serial.print("Simulated frequency: ");
    Serial.print(simulatedFrequency);
    Serial.println(" Hz");

    Serial.print("Signal amplitude: ");
    Serial.println(simulatedAmplitude);

    Serial.println();
  }
  else {
    Serial.println("MODE: REAL EEG - A0");
    Serial.println();
  }

  setupTimer1();
  
  lcd.begin(16, 2);
  lcd.clear();
  lcd.print("EEG Analysis");
  lcd.setCursor(0, 1);
  lcd.print("Init...");
}

// LOOP
void loop() {

  if (windowReady) {
    // INTERRUPTS STOP
    noInterrupts();

    // Copy of the sampled window
    for (uint16_t i = 0; i < windowSize; i++) {
      processingBuffer[i] =
        sampleBuffer[i];
    }

    // The window has been sampled
    windowReady = false;

    // Reset of idx for the next window
    sampleIndex = 0;

    interrupts();

    // AVERAGE CALCULUS
    uint32_t sum = 0;

    for (uint16_t i = 0; i < windowSize; i++) {
      sum += processingBuffer[i];
    }

    float mean =
      (float)sum / windowSize;

    // BAND CALCULUS
    float deltaPower =
      calculateBandPower(1, 4, mean);

    float thetaPower =
      calculateBandPower(4, 8, mean);

    float alphaPower =
      calculateBandPower(8, 14, mean);

    float betaPower =
      calculateBandPower(14, 30, mean);

    float gammaPower =
      calculateBandPower(30, 80, mean);

    // OUTPUT
    Serial.println();
    Serial.println("EEG BAND POWER");

    Serial.print("Delta (0.5-4 Hz): ");
    Serial.println(deltaPower);

    Serial.print("Theta (4-8 Hz):   ");
    Serial.println(thetaPower);

    Serial.print("Alpha (8-14 Hz):  ");
    Serial.println(alphaPower);

    Serial.print("Beta (14-30 Hz):  ");
    Serial.println(betaPower);

    Serial.print("Gamma (30-80 Hz): ");
    Serial.println(gammaPower);

    
    // DOMINANT BAND
    float maxPower = deltaPower;
    const char* dominantBand = "DELTA";

    if (thetaPower > maxPower) {
      maxPower = thetaPower;
      dominantBand = "THETA";
    }

    if (alphaPower > maxPower) {
      maxPower = alphaPower;
      dominantBand = "ALPHA";
    }

    if (betaPower > maxPower) {
      maxPower = betaPower;
      dominantBand = "BETA";
    }

    if (gammaPower > maxPower) {
      maxPower = gammaPower;
      dominantBand = "GAMMA";
    }


    Serial.print("Dominant band: ");
    Serial.println(dominantBand);

    // FOCUS / NOT FOCUS
    bool focused = (betaPower >= maxPower);

    if (focused) {
      Serial.println("FOCUS");
    }
    else {
      Serial.println("NOT FOCUS");
    }

    // LCD UPDATE
    lcd.clear();

    lcd.setCursor(0, 0);
    lcd.print("Band: ");
    lcd.print(dominantBand);

    lcd.setCursor(0, 1);
    if (focused) {
      lcd.print("FOCUS");
    }
    else {
      lcd.print("NOT FOCUS");
    }
  }
}
